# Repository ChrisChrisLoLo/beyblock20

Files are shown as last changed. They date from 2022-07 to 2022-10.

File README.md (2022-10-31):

# beyblock20

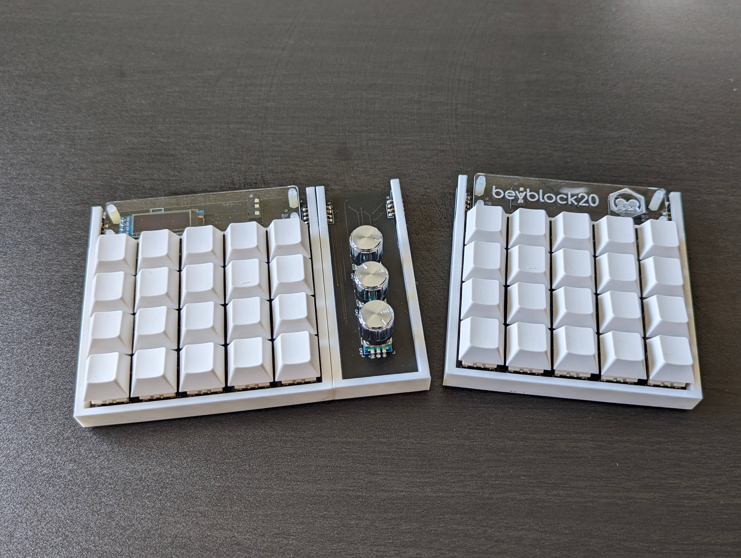
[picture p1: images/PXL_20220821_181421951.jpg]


A 20 key modular macropad that can connect with other elements to form a larger macropad via magnets. This versatile module in combination with the encoder module (knoblin3) can be used to form a 20 key macropad with 3 encoders, a 4x10 ortholinear board, or a 4x10 ortholinear board with 3 encoders! Each module has a Seeeduino XIAO on it, and all of them communicate on an I2C bus. Because of the I2C bus, more kinds modules can be made for an even more fine tuned and customized macropad/keyboard, as well as up to 128 devices to be connected together at once!

Video demo here: https://www.youtube.com/watch?v=Z132qLr78tY

## Status

**beyblock20: alpha stage**

**knoblin3: alpha stage (though case needs mounting holes)**

**mongus48: pre-prototyping phase, do *not* produce**

See more about alpha here: https://github.com/ChrisChrisLoLo/beyblock20/blob/master/alpha.md

Prototyping phase. Firmware is a now working (!!!) though I will refine it to catch hotswap edgecases, as well as make the configuration process easier. I want to try to add capacitors to prevent voltage drops, as well as add some mounting holes to the knoblin3. If there's enough support for this project, I can work on adding new types of modules as well as refine the current ones. Anyone who wishes to expand on this idea are free to use the source files provided. I would produce these if you're looking to tinker and hack (and you're capable of doing so) at your own risk, though more work needs to be done before these are plug and play.

## Features
- A highly customizable framework to tailor your macropad to your needs, when you need to
  - A magnetic connector is on each side of the module, allowing you to connect the components you want, whenever you want
  - Open source, so anyone who wishes to make their own module and publish it is free to
    - Parts could include Display modules, sensors, sliders, LEDs, trackpads, etc.
    - Opens the possibility of a ecosystem of interchangible parts
- Uses hotswap sockets, so you can swap out keys to your hearts content
- Has TTRS jacks that uses the same I2C bus, so having a split keyboard should be doable!
- Aside from the magnetic connector, uses commodity parts, so it should be easy to order and assemble your own!

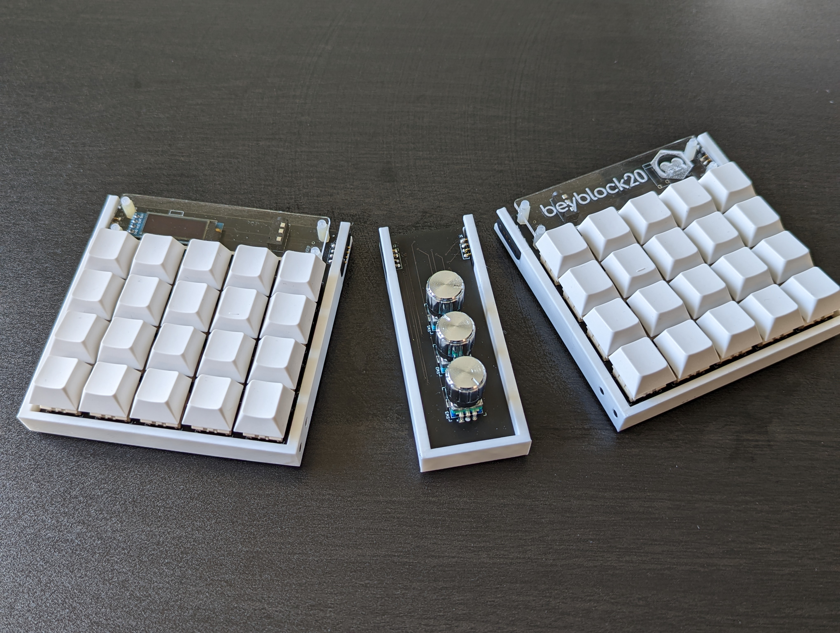
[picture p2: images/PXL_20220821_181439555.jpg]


## Design
This design came out the [Seeedstudio Seeeduino Xiao Keyboard Competition](https://www.seeedstudio.com/seeed-fusion-diy-xiao-mechanical-keyboard-contest.html). The Seeeduino XIAO RP2040 is a great, affordable, little microcontroller. I'm a big fan of the USB C port and castellated pins on it. It's biggest tradeoff was that there aren't as many pins on it as a pro-micro, meaning that you have to think outside the box to get enough pins to make a keyboard out of it. I found this constraint to be really fun, since I pushed me to take an I2C "split" keyboard approach. The beyblock20 also draws inspiration from Zack Freedman's [Mirage Keyboard](https://github.com/ZackFreedman/MiRage), particularly with the idea of an unbounded I2C bus.  

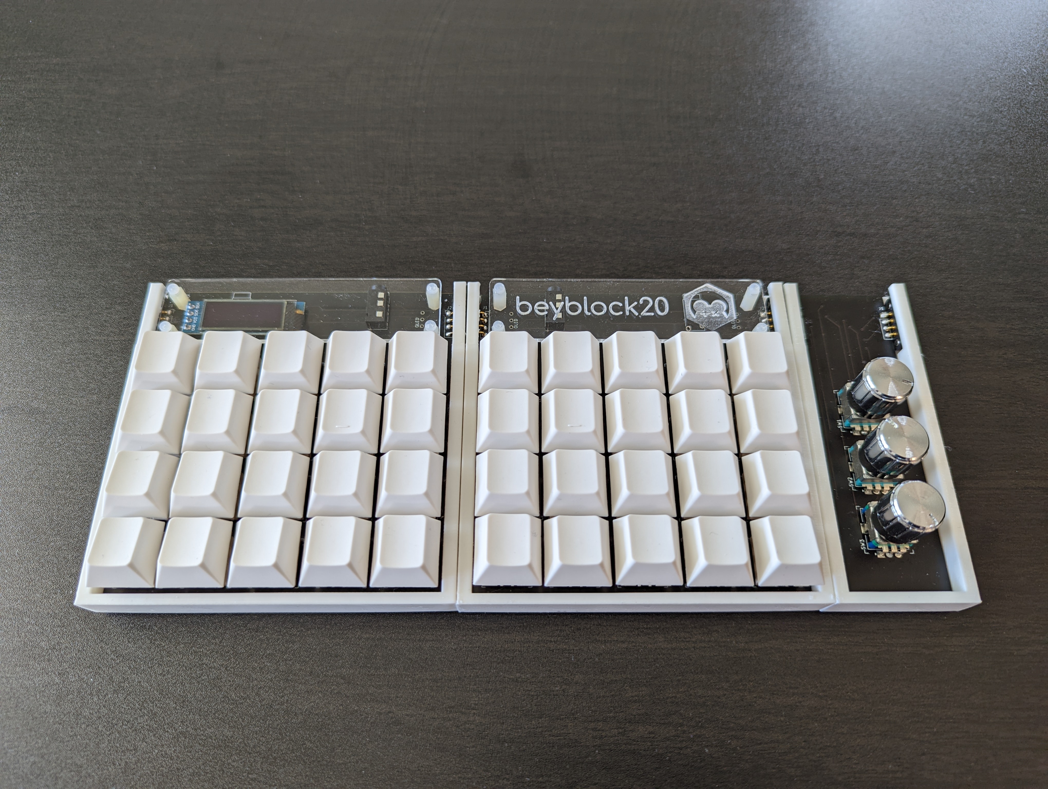
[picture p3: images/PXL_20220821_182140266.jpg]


Thank you to Seeedstudio for manufacturing these boards for free for the competition. I found the [Seeduino Xiao RP2040](https://www.seeedstudio.com/seeed-fusion-diy-xiao-mechanical-keyboard-contest.html) board to be an excellent product, and the community support for said board to be awesome.
<span>
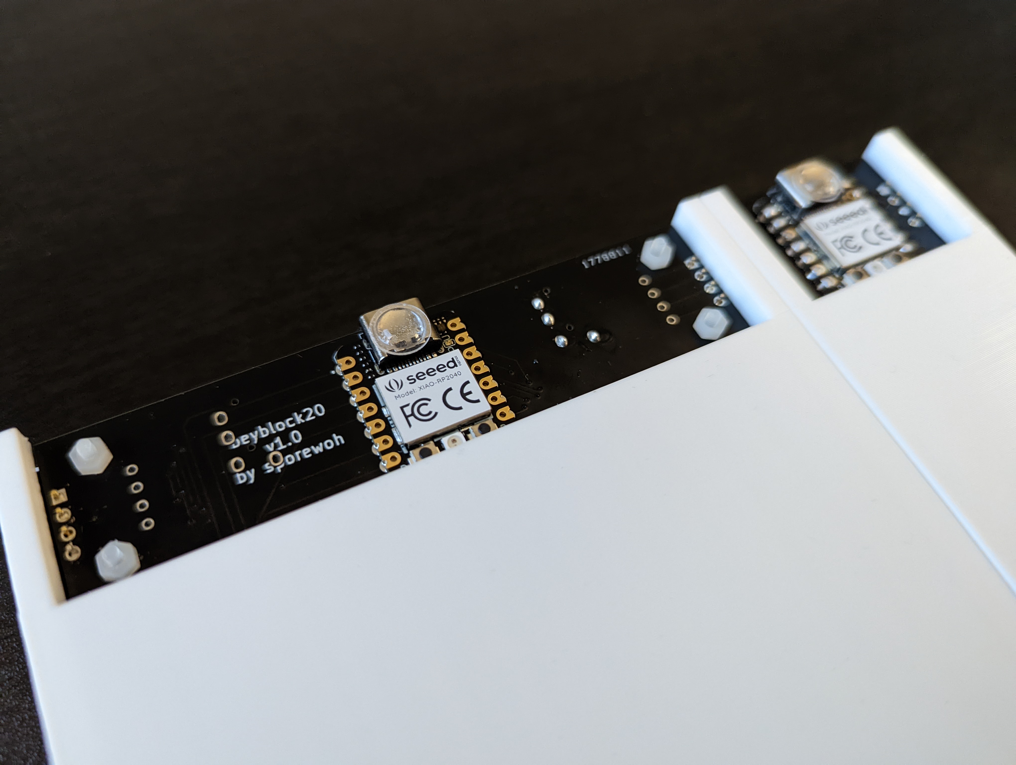
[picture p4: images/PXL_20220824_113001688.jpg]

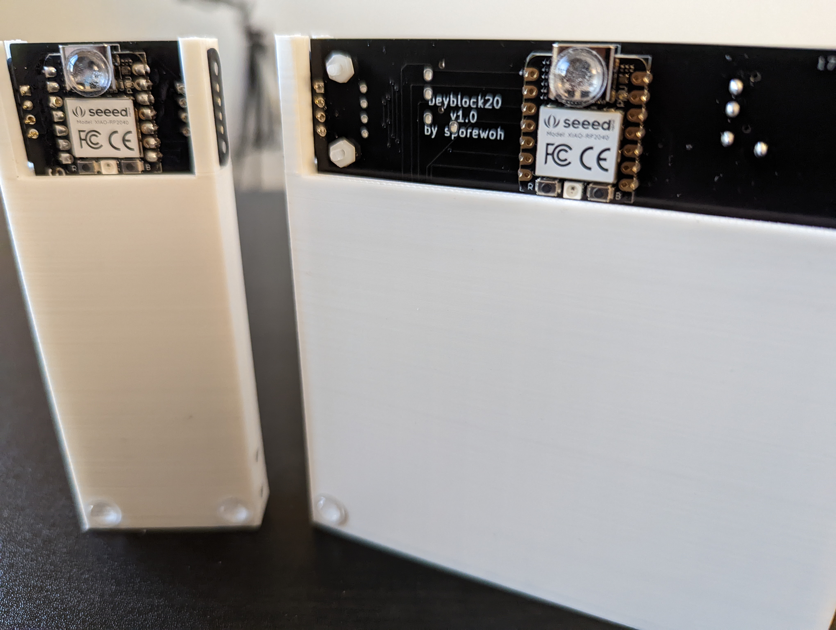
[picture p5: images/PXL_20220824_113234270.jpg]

</span>
## Parts

I will outline the main parts here, though since the design, isn't finalized, you may need a few addtional parts, like screws and such

Beyblock40 BOM (knoblin3 and mongus48 BOM TBD)
| Part | Count | Comment |
|---|---|---|
| Seeeduino XIAO RP2040 | 1 per module | You can try other XIAO variants, though more parts may be required to make something like a wireless beyblock20. Any firmware written will be for the RP2040 |
| 4 pin magnetic connectors | 2 per module | You'll look like ones from here: https://www.adafruit.com/product/5358. I was able to get mine on AliExpress |
| M2 screws/nuts | TBD (you'll want atleast 8 of each) | You'll need some to secure the board to the case, and the cover to the board |
| M2 8mm Male/Female spacer | 4 | Used to secure the acrylic cover to the beyblock20 |
| Acrylic Cover | 1 | SVG in the repository. Optional |
| LL4148 SMD Diodes | 20 | |
| Kailh Hotswap sockets | 20 | 
| 0.91 inch Oled Display | 1 | Optional. Typical Oled Display. NOTE: You can only have one per I2C bus, since it's not (easily) possible to have multiple displays of the same type display different things on the same I2C bus 
|3mm diameter and 2mm long neodymium magnets| 4 per module| Part of the secret sauce! This is subject to change as the case design evolves |

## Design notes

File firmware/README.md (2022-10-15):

# Firmware

## Requirements
You want to flash CircuitPython 8.0.0 or later on your boards.
For now this might even mean using the beta version.

## Installation
Run `./upload.sh bc` or `./upload.sh bp` depending on if you want to upload the beyblock20 controller (`bc`) firmware, or the beyblock20 peripheral firmware(`bp`) firmware. Running `./upload.sh kp` will now upload knoblin3 peripheral software. Windows users may need to write a cmd script that effectively copies over source files to their RP2040

## General archetecture
For the most part, this is just a few constructs built on top of KMK. This means you should get the full features of KMK.

beyblock20 works with the idea of controllers and peripherials (think I2C if you're familiar with that).

One module acts as the controller. This controller stores all the keymap information on it, so you only need to update it if you want to update your layout. In the controller keymap, you can place keys of each module you have, as well as define what modules you have. Down the road, I could likely write a helper function that stream lines the process a bit. 

All other modules are expected to be programmed as peripherals. These peripherals are pretty dumb, in that they don't store any keymap information. Instead, they report what keys got pressed when inquired by the controller. They're also capable of executing XYZ operations based on what the controller sends it (though this aspect hasn't been used yet). This means you cannot use a peripheral stand-alone. This is the trade-off for only needing to program one microcontroller for basic layout changes.

Caveats:
- You may need to explicitly define an address in some situations, espectially in the case that you're using more than 1 beyblock40 peripheral or 1 knoblin3 peripheral.
- You cannot have multiple OLEDs of the same type together, since they generally share the same I2C address.

See the source files for a better understanding

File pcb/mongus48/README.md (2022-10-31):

# Pre-prototyping phase: do NOT print me
I still need to validate that the shift registers are working as expected

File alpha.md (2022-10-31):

# Welcome to Alpha!

beyblock20 and knoblin3 are now in states that I consider to be usable by eager alpha testers!
(mongus48 pre-prototyping still underway: I need the shift registers to come in to confirm that it works)

(the knoblin3 case also needs mounting holes :( )

# What you get
You get get to be on the bleeding edge of modular keyboard technology!

I have the KMK firmware working, and with a period of testing, I think I got it to a point where it all seems to generally work enough to use casually.

With this alpha program, you get modular keyboards _today_, open-source files to tweak to your liking, and the ability to contribute to this project and shape it. 

I've confirmed that the rotary encoders work (aside from button presses, though adding support should be doable), TRRS works, I2C hotswap is generally stable, etc.
I'm confortable enough to suggest technically apt people to try this out if they wanted to tinker around.

If you're looking to make a modular keyboard of your own, you also get to play around with my implementation of it, and play around with it for yourself.

If you want to build a module on top of this system, you're more than free to do so, and get bragging rights for making the next killer module!
  
# Disclaimer
To be explicit, the project is provided "as-is", and should not be considered to be a product but rather a side-project. There is no liability or promised support for this project. You will be expected to have some technical knowledge to diagnose any issues you encounter at this phase of the project. Issues in Github may not cover all issues you will encounter yourself.

# What you (ideally) need

Some degree of technical literacy/ willingness to learn and tinker:
- I think there's still some edge cases here and there with general UX that I haven't tended to.
Being able to debug KMK (as well as the stuff I built on top of it) for yourself will give you an ability to unstuck yourself if needed.
- I will try to document issues when I encounter them in the issues section.
- I will try to help answer questions as they come up, but I cannot guarentee that I can put hands to keyboard times into software refinements.

Willingness to get new revisions:
- The PCB dimensions should be fairly stable, though there is a case redesign in the works (e.g. I need to add mounting holes to the cases).
In the interests of making the best project possible, I reserve the ability to make new (breaking) revisions if absolutely needed.
- The most likely case is I want to add a few new components, in which case you'll have to get a new board to get the features from said components.
- This point is to emphasize that you will likely want a way to be able to make new cases/obtain new pcbs, and that the current ones aren't final. I would not recommend alpha to anyone who could only affort 1 keyboard for the next few years.

Patience and kindness:
- The two points above are reinforcements of this point. While I think there's a few more things I personally want to add to the project, I want people
be able toy around with the project as they want if I need to reprioritize this project in my life. By making this sort of Alpha program, I hope to release a prototype others can play with and build apon. I make no promises about where this project will go, but only what it currently is
something usable to interested parties without being obligated to fix every edgecase and problem that arises
- Please be understanding for any new features/fixes. I cannot promise anything, but I'll try to help where I can when I get the chance
- Feel free to create an issue if you want advice or help. Someone may be able to answer a question you have

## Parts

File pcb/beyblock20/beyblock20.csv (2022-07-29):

Id | Designator | Package | Quantity | MPN | Supplier and ref
1 | U1 | Seeeduino XIAO-MOUDLE14P-2.54-21X17.8MM | 1 | Seeed XIAO RP2040
2 | D20,D19,D18,D17,D16,D15,D14,D13,D12,D11,D10,D9,D8,D7,D6,D5,D4,D3,D2,D1 | D_MiniMELF | 20 | LL4148

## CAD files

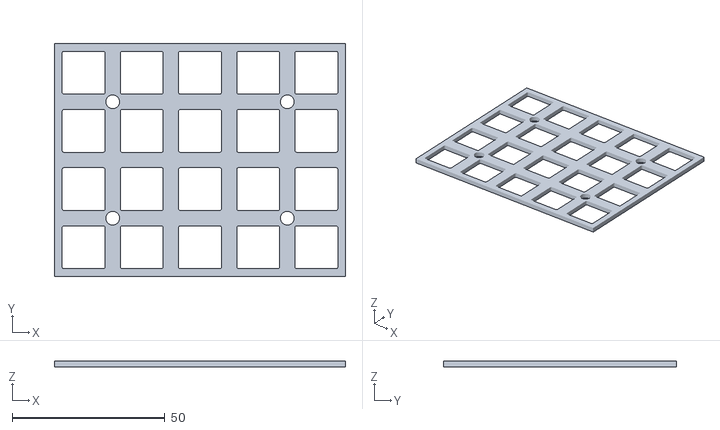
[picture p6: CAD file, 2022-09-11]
case/plate.stl
95.2 x 76.2 x 2.00

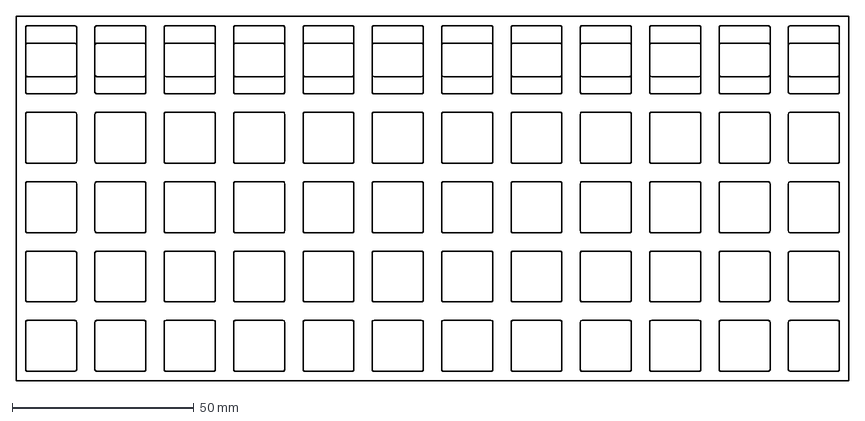
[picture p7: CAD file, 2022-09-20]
outlines/mongus48/plate-2022-09-19T00 32 47.840Z.dxf
228.6 x 100.0 mm

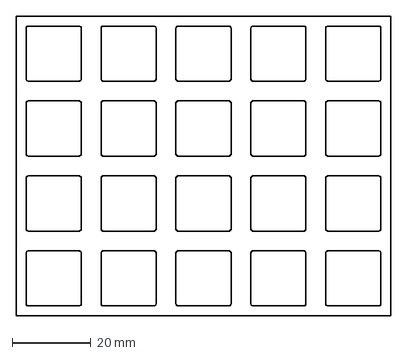
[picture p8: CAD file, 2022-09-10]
outlines/plate-2022-09-10T23 07 37.106Z.dxf
95.2 x 76.2 mm

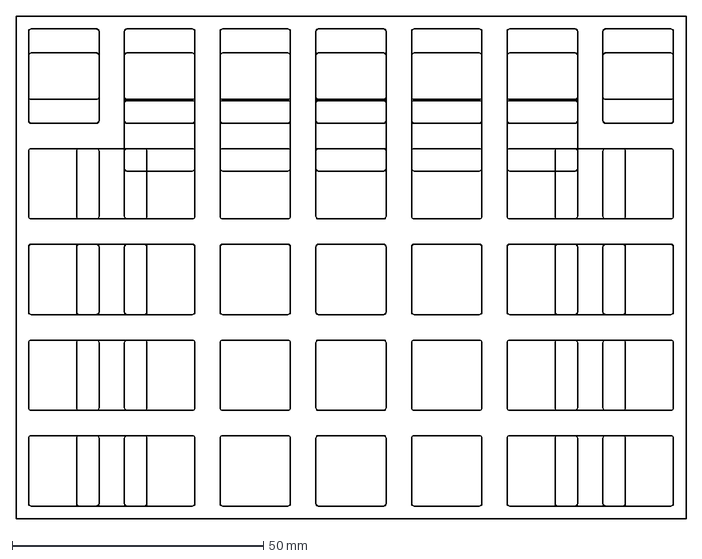
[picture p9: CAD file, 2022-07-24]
outlines/v3/plate-2022-07-24T20 10 04.936Z.dxf
133.3 x 100.0 mm

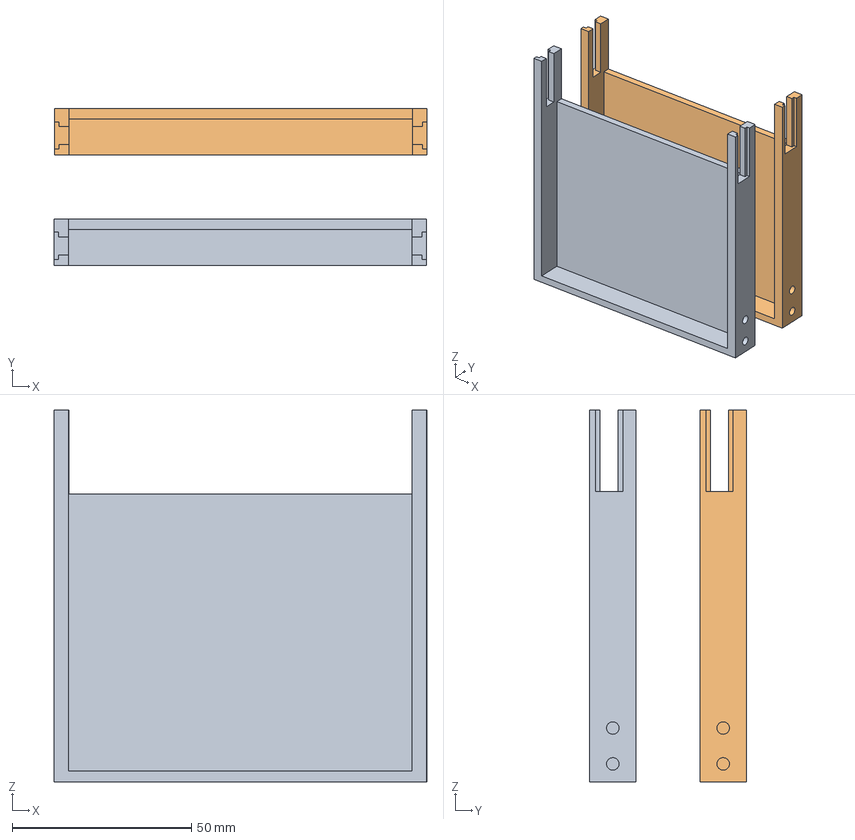
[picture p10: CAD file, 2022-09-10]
case/beyblock20.3mf
104.0 x 43.8 x 103.6 mm
beyblock20.stl x 2

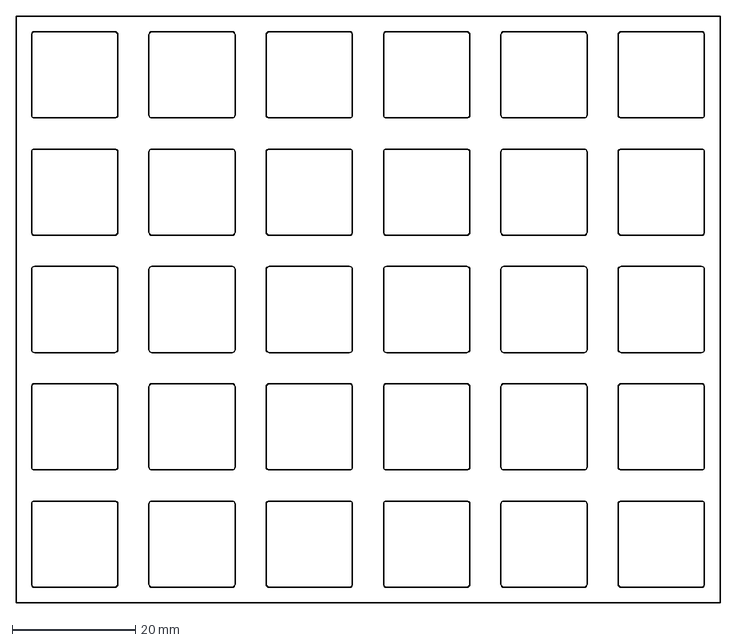
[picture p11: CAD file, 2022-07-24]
outlines/plate-2022-07-24T01 53 18.030Z.dxf
114.3 x 95.2 mm

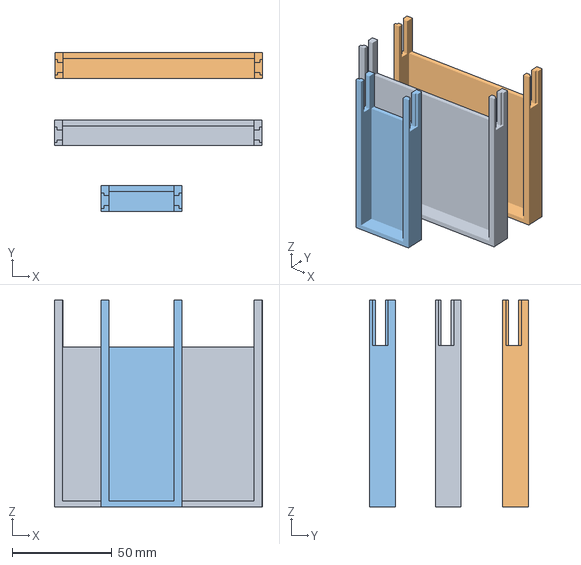
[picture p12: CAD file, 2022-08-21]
case/beyblockv1.3mf
104.2 x 79.8 x 103.6 mm
beyblock20.stl x 2
knoblin3.stl

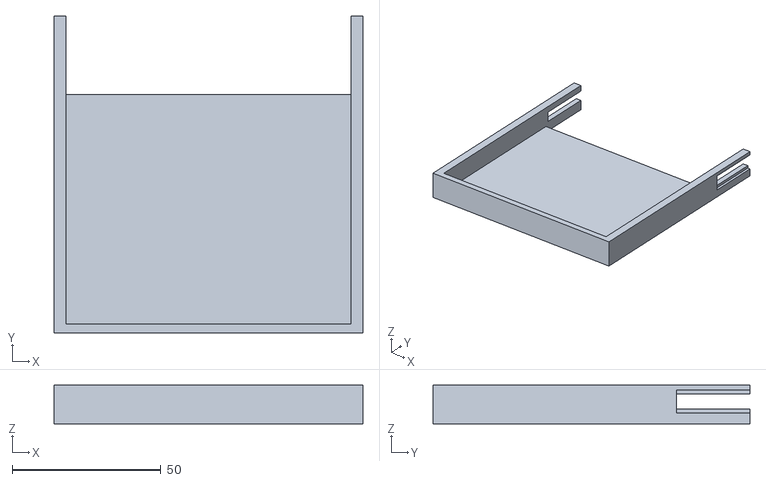
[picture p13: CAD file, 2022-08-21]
case/Body1.stl
103.8 x 106.6 x 13.0

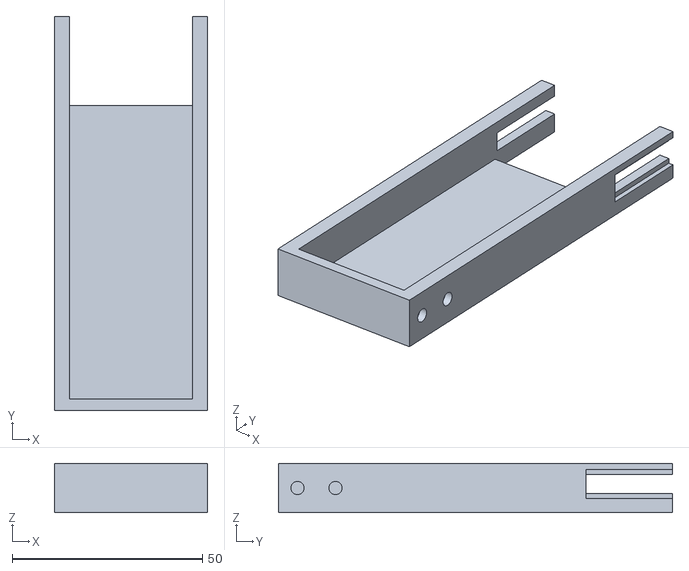
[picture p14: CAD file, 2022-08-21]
case/knoblin3.stl
40.4 x 103.6 x 13.0

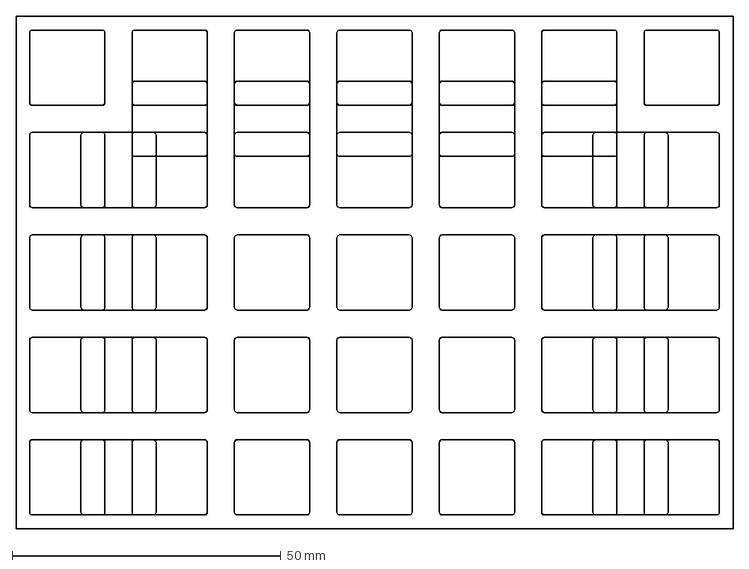
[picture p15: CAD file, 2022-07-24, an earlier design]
outlines/v2/plate-2022-07-24T18 42 40.353Z.dxf
133.3 x 95.2 mm

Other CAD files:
case/beyblock20.stl

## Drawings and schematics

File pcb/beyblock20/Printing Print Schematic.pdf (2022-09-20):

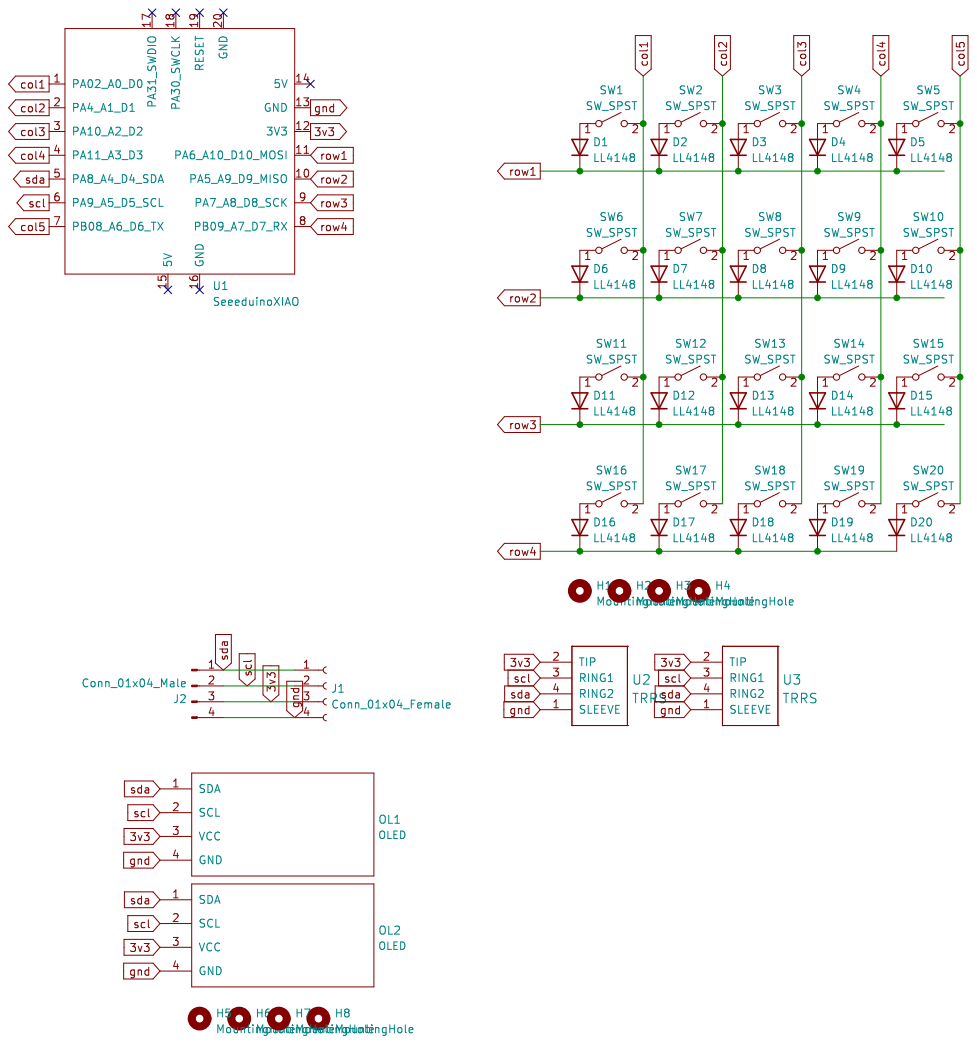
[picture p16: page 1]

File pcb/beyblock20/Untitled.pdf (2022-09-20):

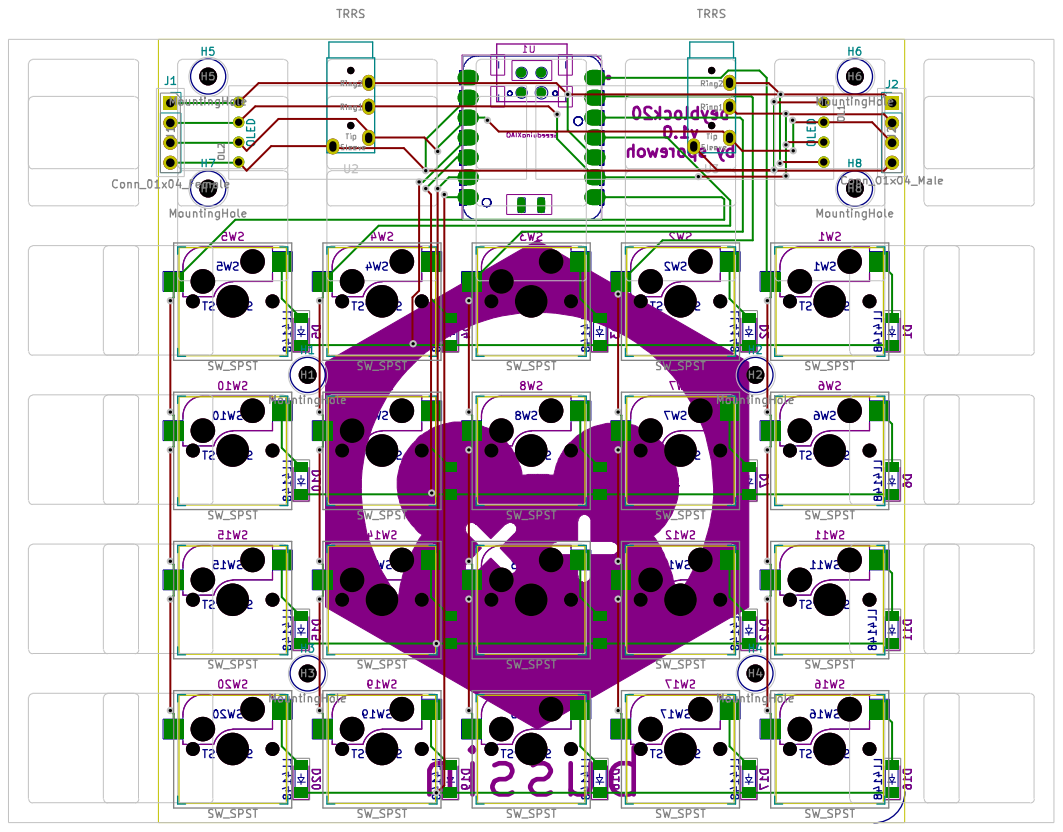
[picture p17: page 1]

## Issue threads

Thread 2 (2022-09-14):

Add I2C Controller brownout mitigations

ChrisChrisLoLo, 2022-09-14:
When you add on a module to the controller hotswap style (controller is powered on), it has a tendency to shut down, if only for a brief period of time.

I suspect the cause is some sort of brownout, where the peripheral drains too much current from the controller too quickly.

The easiest first thing to try might be to add a reservoir capacitor. I'm not sure what the capacitance should generally be, and I'm not even sure if it will help or not

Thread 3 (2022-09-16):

Add I2C bus reset

ChrisChrisLoLo, 2022-09-16:
See if it's possible to reset the I2C bus using software in the event of a timeout

https://github.com/adafruit/circuitpython/issues/2635

ChrisChrisLoLo, 2022-09-18:
Roughly speaking, I've now done this by adding watchdogs to the peripherals.

Closed 2022-09-18.

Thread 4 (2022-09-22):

Can you support ZMK, sir?

kien242, 2022-09-22:

ChrisChrisLoLo, 2022-09-23:
Hey! I think one day, I could give this a look at, I think I'd be nice given that XIAOs have wireless flavours.

I don't think I can support ZMK as easily as I did for KMK, since I'd have to figure out how to jig my own custom I2C code into the ZMK C codebase. The easiest way would probably to make a fork and bake some hex files or the like, though it'd be nice if I could either find a way to add external "libraries" to my own ZMK firmware, or get some code into ZMK.

I would love to have support for ZMK one day, since I think it would feed nicely into some of my other upcoming modules, though I don't think I have the bandwidth to look into this at the moment. If anyone is a ZMK expert and would like to take the lead on this, I'm all for it!

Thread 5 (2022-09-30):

Adding more magnetic connector

YapZanan, 2022-09-30:
Is it possible to add more magnetic connector in north and south of the pcb? So every module can be arrange from every other side.

YapZanan, 2022-09-30:
After looking the gerber file that you provided, I think that might be possible, but I have to resize the north and south size to be bigger. I think I will edit the resistor to THT instead of SMD for easier building.

ChrisChrisLoLo, 2022-09-30:
Thanks for your interest!

I don't know if adding a north and south connector is currently within scope of this project. I think the biggest design challenges would include what you've mentioned: a larger footprint, new challenges to fit said PCB in a case, specifying an interface for vertical connection, and the fact that we'd have to double up on magnetic connectors, which isn't super cheap at the moment.

For the current scope of the project, I alos want to try to avoid grids  (i.e. there's i2c bus loops introduced), since currently I have no idea what implications that has for the I2C bus. Maybe down the line, with another modular keyboard, this could be explored.

An alternative idea might be to make a taller module if you want an L shaped configuration. Something that would be cool that wouldn't require any changes to the beyblock interface would be to make a tall module where you could either put the beyblock not only on each side, but choose if you want to put it on the upper part of the  side, or put it on the lower part of the side side. Beyblock20 now works with KMK, so if you'd like to play around with it a bit, it's something you could certainly try, as well as any other module idea's you have.

With the THT vs SMD discussion, you're free to make your own THT variant, though I think the reason why I stuck with SMD is that it should hopefully make the board look cleaner, and to hopefully avoid any clearance issues. I'm hoping that the package size I picked is as easy as to solder as the diodes.

xor256, 2022-10-21:
no, normal strong neodyme magnets, no small conectors

Closed 2022-10-31.

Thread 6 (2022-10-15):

Disable USB drive module in CircuitPython

ChrisChrisLoLo, 2022-10-15:
Unless we want to upload new firmware, we should probably turn off the USB drive appearing from the RP2040

ChrisChrisLoLo, 2022-10-15:
https://learn.adafruit.com/customizing-usb-devices-in-circuitpython/circuitpy-midi-serial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

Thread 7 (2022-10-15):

Finalize case mounting solution

ChrisChrisLoLo, 2022-10-15:
I want to finalize how the case gets mounted to the board. Currently, you should be able to to drive screws through the case and the board, though I may want to throw heat inserts into the mix

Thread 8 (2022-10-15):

OLED doesn't work when other modules are attached

ChrisChrisLoLo, 2022-10-15:
OLED seems to work when running a controller with no peripherals. It does _not_ work when other modules are attached. Find out why.

I wonder if there's some sort of I2C lock issue or the like occurring, though further investigation would be needed.

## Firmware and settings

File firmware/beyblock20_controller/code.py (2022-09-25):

print("Starting")

from kb import KMKKeyboard
from kmk.keys import KC
from kmk.extensions.media_keys import MediaKeys
from kmk.modules import tapdance
from kmk.modules.cg_swap import CgSwap
from kmk.modules.modtap import ModTap
from kmk.modules.tapdance import TapDance
from kmk.modules.layers import Layers
from kmk.modules.mouse_keys import MouseKeys
from kmk.modules.rapidfire import RapidFire

TAP_TIME = 300

keyboard = KMKKeyboard()

keyboard.debug_enabled = True

# oled_ext = Oled(
#     keyboard.i2c,
#     OledData(
#         corner_one={0:OledReactionType.STATIC,1:["layer"]},
#         corner_two={0:OledReactionType.LAYER,1:["1","2","3","4"]},
#         corner_three={0:OledReactionType.LAYER,1:["base","raise","lower","adjust"]},
#         corner_four={0:OledReactionType.LAYER,1:["qwerty","nums","shifted","leds"]}
#     ),
#     toDisplay=OledDisplayMode.TXT,
#     flip=False
#     )

# init_display(keyboard.i2c)

media = MediaKeys()

# keyboard.extensions = [oled_ext, media]
keyboard.extensions = [media]


layers_ext = Layers()
cg_swap = CgSwap()
modtap = ModTap()
mouse_keys = MouseKeys()
rapid_fire = RapidFire()
tap_dance = TapDance()
tap_dance.tap_time = 150

modtap.tap_time = TAP_TIME

keyboard.modules = [layers_ext, cg_swap, modtap, mouse_keys, rapid_fire, tap_dance]

# Cleaner key names
_______ = KC.TRNS
XXXXXXX = KC.NO


STANDARD = 0
# layer where GUI is swapped.
# We use this instead of the GUI swap feature
# as the swap doesn't seem to work with ModTap
GUI_SWAP = 1 

LOWER = 2
RAISE = 3

# TODO: look into KMK bug where pressing KC.LT(XX) and then pressing KC.MO(XX) breaks everything
LOWER_RAISE = 4


keyboard.keymap = [
    [   
        # left half
        KC.Q,KC.W,KC.E,KC.R,KC.T,
        KC.A,KC.S,KC.D,KC.F,KC.G,
        KC.Z,KC.X,KC.C,KC.V,KC.B,
        KC.LT(LOWER_RAISE, KC.ESC, tap_time=TAP_TIME),KC.LGUI,KC.MT(KC.TAB, KC.LCTRL, tap_interrupted=True),KC.MO(LOWER),KC.SPACE,
        
        # right half
        KC.Y,KC.U,KC.I,KC.O,KC.P,
        KC.H,KC.J,KC.K,KC.L,KC.SCOLON,
        KC.N,KC.M,KC.COMMA,KC.DOT,KC.SLASH,
        KC.MO(RAISE),KC.MT(KC.BSPC, KC.LSHIFT),XXXXXXX,KC.LALT,KC.ENTER,

        # encoders
        KC.MS_LEFT,KC.MS_RIGHT,
        KC.MW_UP,KC.MW_DOWN,
        KC.AUDIO_VOL_DOWN,KC.AUDIO_VOL_UP,
    ],
    [
        KC.Q,KC.W,KC.E,KC.R,KC.T,
        KC.A,KC.S,KC.D,KC.F,KC.G,
        KC.Z,KC.X,KC.C,KC.V,KC.B,
        KC.LT(LOWER_RAISE, KC.ESC, tap_time=TAP_TIME),KC.LCTRL,XXXXXXX,KC.MT(KC.TAB, KC.LGUI, tap_interrupted=True),KC.LT(LOWER, KC.SPACE, tap_interrupted=True),

        KC.Y,KC.U,KC.I,KC.O,KC.P,
        KC.H,KC.J,KC.K,KC.L,KC.SCOLON,
        KC.N,KC.M,KC.COMMA,KC.DOT,KC.SLASH,
        KC.MO(RAISE),KC.TD(KC.MT(KC.BSPC, KC.LSHIFT), KC.BSPC),XXXXXXX,KC.LALT,KC.ENTER,

        KC.MS_LEFT,KC.MS_RIGHT,
        KC.MW_UP,KC.MW_DOWN,
        KC.AUDIO_VOL_DOWN,KC.AUDIO_VOL_UP,
    ],
    [
        KC.EXCLAIM,KC.AT,KC.HASH,KC.DOLLAR,KC.PERCENT,
        KC.TILDE,KC.UNDERSCORE,KC.PLUS,KC.LEFT_CURLY_BRACE,KC.RIGHT_CURLY_BRACE,
        KC.PIPE,_______,_______,_______,_______,
        XXXXXXX,XXXXXXX,XXXXXXX,XXXXXXX,XXXXXXX,

        KC.CIRCUMFLEX,KC.AMPERSAND,KC.ASTERISK,KC.LEFT_PAREN,KC.RIGHT_PAREN,
        KC.LEFT,KC.DOWN,KC.UP,KC.RIGHT,KC.DOUBLE_QUOTE,
        _______,_______,_______,_______,_______,
        KC.MO(LOWER_RAISE),XXXXXXX,XXXXXXX,XXXXXXX,XXXXXXX,

        _______,_______,
        _______,_______,
        _______,_______,
    ],
    [
        KC.N1,KC.N2,KC.N3,KC.N4,KC.N5,
        KC.GRAVE,KC.MINUS,KC.EQUAL,KC.LBRACKET,KC.RBRACKET,
        KC.BSLASH,_______,_______,_______,_______,
        XXXXXXX,XXXXXXX,XXXXXXX,XXXXXXX,KC.MO(LOWER_RAISE),

        KC.N6,KC.N7,KC.N8,KC.N9,KC.N0,
        KC.LEFT,KC.DOWN,KC.UP,KC.RIGHT,KC.QUOTE,
        _______,_______,_______,_______,_______,
        XXXXXXX,XXXXXXX,XXXXXXX,XXXXXXX,XXXXXXX,

        _______,_______,
        _______,_______,
        _______,_______,
    ],
    [
        KC.RESET,_______,_______,_______,_______,
        KC.F1,KC.F2,KC.F3,KC.F4,KC.F5,
        KC.F7,KC.F8,KC.F9,KC.F10,KC.F11,
        XXXXXXX,KC.DF(GUI_SWAP),XXXXXXX,KC.DF(STANDARD),XXXXXXX,

        _______,_______,_______,_______,KC.DEL,
        KC.F6,KC.AUDIO_VOL_DOWN,KC.AUDIO_VOL_UP,_______,_______,
        KC.F12,_______,_______,_______,_______,
        XXXXXXX,XXXXXXX,XXXXXXX,XXXXXXX,XXXXXXX,

        _______,_______,
        _______,_______,
        _______,_______,
    ],
]

if __name__ == '__main__':
    keyboard.go()

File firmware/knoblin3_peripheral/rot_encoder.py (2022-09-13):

import keypad
import rotaryio

# Lifted from KMK and modified
# Mostly need it to scan for changes
class RotaryioEncoder():
    def __init__(self, pin_a, pin_b, offset, divisor=4):
        self.encoder = rotaryio.IncrementalEncoder(pin_a, pin_b, divisor)
        self.position = 0
        self.offset = offset
        self._pressed = False
        self._queue = []

    @property
    def key_count(self):
        return 2

    def scan_for_changes(self):
        position = self.encoder.position

        if position != self.position:
            self._queue.append(position - self.position)
            self.position = position

        if not self._queue:
            return

        key_number = self.offset
        if self._queue[0] > 0:
            key_number += 1

        if self._pressed:
            self._queue[0] -= 1 if self._queue[0] > 0 else -1

            if self._queue[0] == 0:
                self._queue.pop(0)

            self._pressed = False

        else:
            self._pressed = True

        return keypad.Event(key_number, self._pressed)

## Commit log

2022-07-24 board init
    [beyblock20.kicad_sch, plate-2022-07-24T18 42 40.353Z.dxf]
2022-07-24 finish initial pcb
    [beyblock20.kicad_sch, plate-2022-07-24T20 10 04.936Z.dxf]
2022-07-24 test gerbers
    [beyblock20-B_Cu.gbr, beyblock20-B_Mask.gbr, beyblock20-B_Paste.gbr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]
2022-07-26 add submodues and exports
    [beyblock20.csv]
2022-07-26 add trrs
    [beyblock20-B_Cu.gbr, beyblock20-B_Mask.gbr, beyblock20-B_Paste.gbr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]
2022-07-29 produce outputs
    [beyblock20.csv]
2022-07-29 add knoblin3
    [knoblin3-B_Cu.gbr, knoblin3-B_Mask.gbr, knoblin3-B_Paste.gbr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]
2022-08-21 add new files
    [Body1.stl, beyblock20.stl, beyblockv1.3mf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]
2022-09-10 Add plate outlines
    [beyblock20.3mf, plate-2022-09-10T23 07 37.106Z.dxf]
2022-09-11 add updated stls
    [beyblock20.stl, plate.stl]
2022-09-12 init I2C communication
2022-09-12 basic I2C communication
2022-09-12 stabilze I2C code
2022-09-13 Get really rough I2C POC working
2022-09-13 drastically improve i2c stability
    [code.py, i2c_scanner.py]
2022-09-13 Add offset to i2c scanner
2022-09-14 generalize I2C scanner
2022-09-14 add gui swap layer
    [code.py]
2022-09-15 use i2c device
2022-09-16 Add peripheral watchdog to prevent I2C lockups
    [code.py, i2c_scanner.py]
2022-09-18 update knoblin to v2.0
    [knoblin3.kicad_sch]
2022-09-20 init mongus48
    [mongus48.kicad_sch, plate-2022-09-19T00 32 47.840Z.dxf]
2022-09-20 (broken) add firmware updates
    [code.py, i2c_scanner.py]
2022-09-27 update beyblock20 and knoblin3
    [beyblock20.kicad_sch]
2022-09-27 add gerbers
2022-09-29 add mongus48. make beyblock updates
    [beyblock20.kicad_sch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]
